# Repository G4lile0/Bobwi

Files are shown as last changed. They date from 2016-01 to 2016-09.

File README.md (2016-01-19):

# Bobwi

<b>Warning: This is a prototype, some parts need to be improved.</B>

Robot, inspired by Bob and Zowi, if you want more information regarding Zowi, please visit:
www.bq.com/zowi
http://diwo.bq.com/en/zowi-cc-by-sa/

If you want to replicate this dance:  https://youtu.be/4x4xa3OTv4A

First you need to calibrate the servos:
https://github.com/G4lile0/Bobwi/tree/master/code/v1/arduino/v1/calibration

Then use that values, to load the Dance code.
https://github.com/G4lile0/Bobwi/tree/master/code/v1/arduino/v1/smooth_criminal

If you want to control the robot from your Android phone: 

Download the official "Zowi App" from bq

Configure the bluetooth module using this code:
https://github.com/G4lile0/Bobwi/tree/master/code/v2/arduino/code/hc06_bt_config

Then load the Zowi base v2 software:
https://github.com/G4lile0/Bobwi/tree/master/code/v2/arduino/code/ZOWI_BASE_v2

##License



All these products are released under [Creative Commons Attribution-ShareAlike 4.0 International License](http://creativecommons.org/licenses/by-sa/4.0/).

Todos estos productos están liberados mediante [Creative Commons Attribution-ShareAlike 4.0 International License](http://creativecommons.org/licenses/by-sa/4.0/).

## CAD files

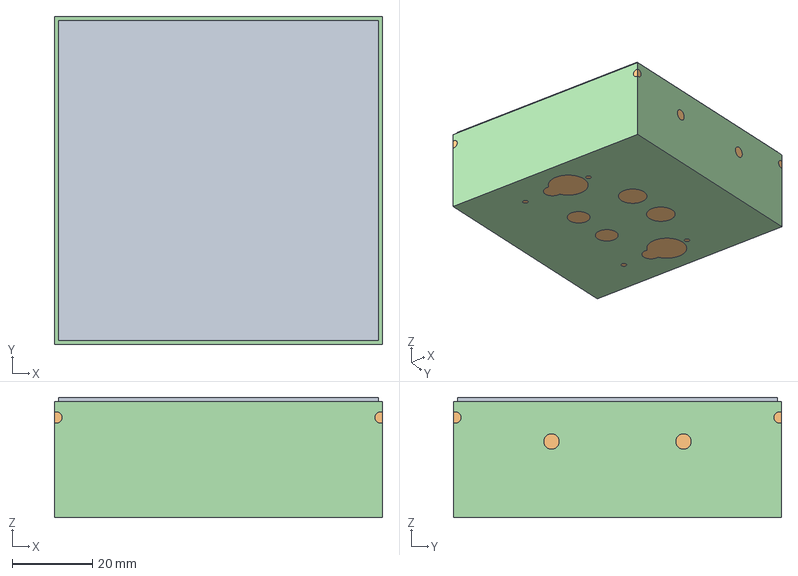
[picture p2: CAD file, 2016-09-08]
parts/freecad/base_matrix_led_v1_6.fcstd
82.0 x 82.0 x 30.0 mm
Box_int
Box_Ext
MONTEINO003

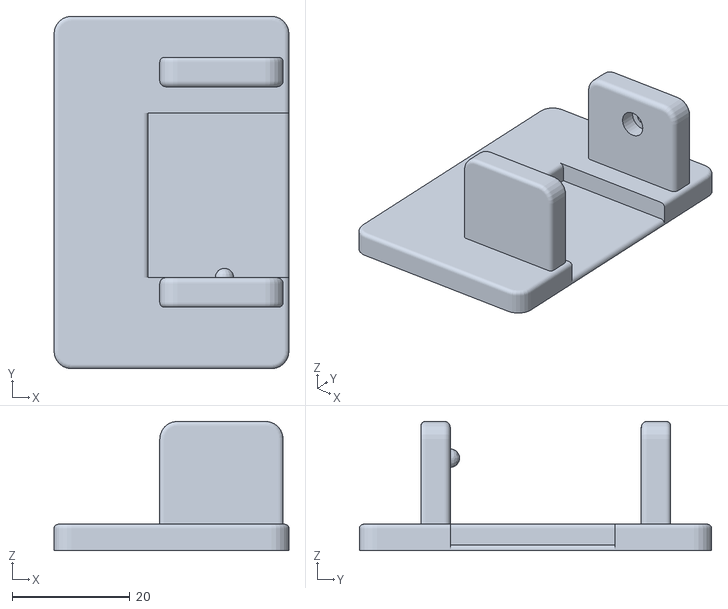
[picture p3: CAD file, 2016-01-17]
parts/stl/foot_v3_left.stl
40.0 x 60.0 x 22.0

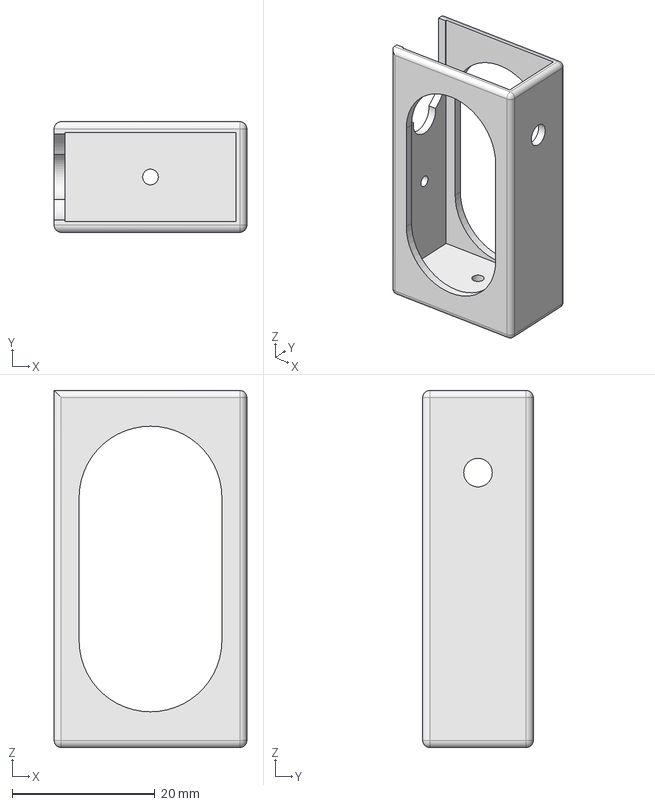
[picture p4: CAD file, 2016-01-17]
parts/freecad/leg_v5.fcstd
27.0 x 15.5 x 50.0 mm

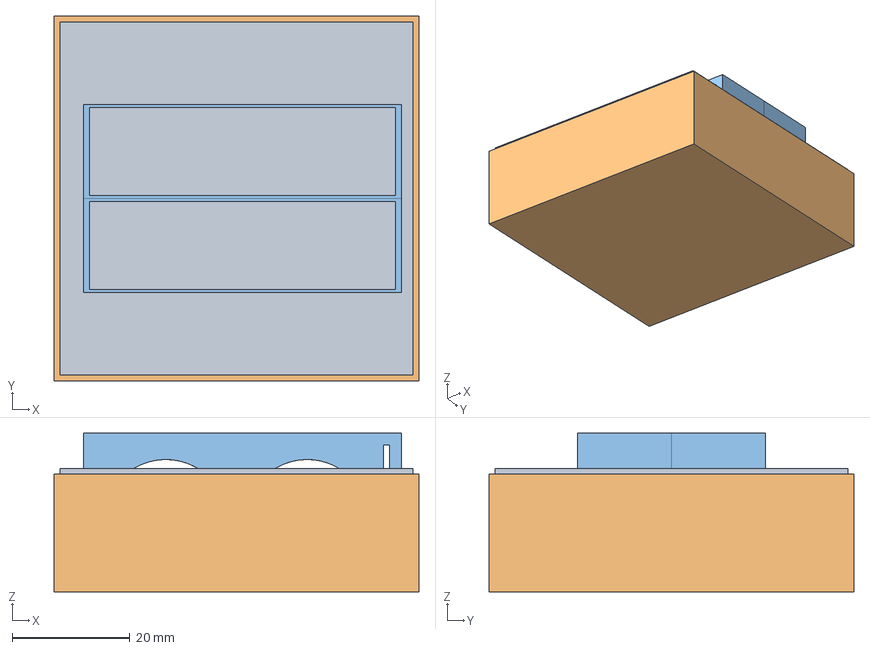
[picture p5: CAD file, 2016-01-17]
parts/freecad/base_v35.fcstd
62.0 x 62.0 x 27.0 mm
Box_int
Box_Ext

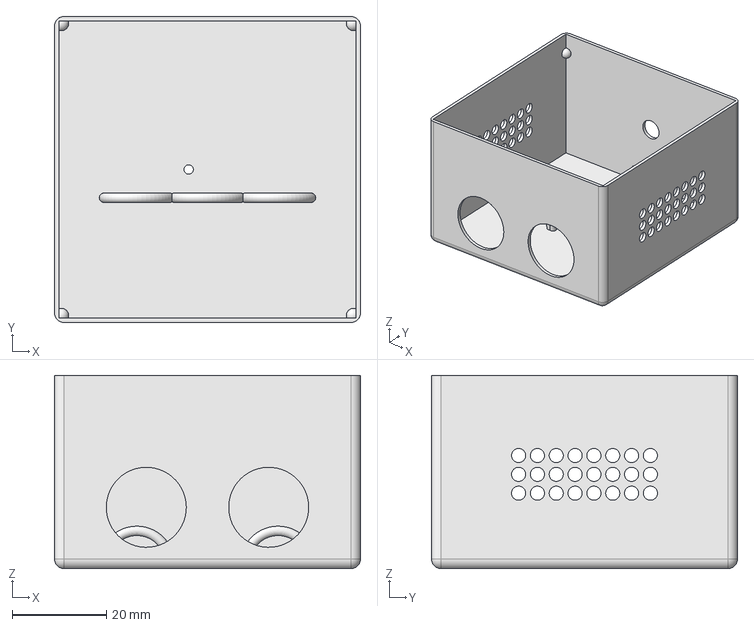
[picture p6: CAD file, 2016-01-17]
parts/freecad/head_v21.fcstd
65.0 x 65.0 x 41.0 mm

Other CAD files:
parts/stl/foot_v3_right.stl
parts/freecad/foot_v3.fcstd
parts/stl/base_matrix_led_v1_6.stl
parts/stl/base_v35.stl
parts/stl/head_v21.stl
parts/stl/leg_v5.stl

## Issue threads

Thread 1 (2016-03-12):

Instructions for assembly

JimSVMI83, 2016-03-12:
Awesome project I'm printing the parts now.  Can you provide assembly instructions or some detailed pictures of the insides.  Would save time in wiring together if not thanks anyway great job

Jim

dalcon, 2016-05-10:
He configurado el hc-06, con el softw propuesto, y en principio parece que todo bien, pero cuando abro la aplicación, empareja bien el dispositivo con bobwi, pero no hace ningun movimiento, como si no recibiera señal, ¿hay que hacer algun paso mas?

G4lile0, 2016-05-11:
Has probado a cargar el código del baile "Bobwi/code/v1/arduino/v1/smooth_criminal" .. mas que nada para comprobar que funcionen bien los servos..

Incluso sin conexión BT debería de moverse de forma aleatoria..

dalcon, 2016-05-11:
Si, los servos se mueven correctamente, cargandole las instrucciones a mano.
El problema es de comunicación.
De echo si monitorizo el puerto serie veo que envía el primer movimiento de la app zowi, M 1 100 correctamente, pero despues comienza a enviar solamente el caracter 'S'
con cualquier pulsación.

cparrapa, 2016-09-09:
Dalcon serán los Baudios? yo tengo el mismo problema primero use HC-06 por que el código era para eso y funciono!, luego cambie a un HC-05 como aparece en la lista de partes y me conecta pero no hay movimento :S

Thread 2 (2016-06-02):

Right Leg Servo doesn't move

cparrapa, 2016-06-02:
Hi G4lile0

Thanks  to other comments i make it work and connect easily with HC-06 Bluetooth module, but somehow the Right Leg Servo doesn't move (already double check different servos, the board and connections), also doesn't make sounds (buzzer pin 10). Is a little bit confusing the libraries of Zowi some of them have bugs and switching to Bitbloq generate some kind of redundancy in variables. Your libraries seems better for Bluetooth, are the last ones?

Overall great job! and thanks.

G4lile0, 2016-09-08:
Solved.. issue related to the different arduino pin configuration of Zowi and Bobwi,

Closed 2016-09-08.

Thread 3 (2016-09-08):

Chasis para matriz led

Ayunken, 2016-09-08:
Hola G4lile0.
He visto que has hecho una nueva base para la cabeza para añadir una matriz de leds en un video. Es posible que publiques los diseños 3D de la nueva cabeza. Gracias

G4lile0, 2016-09-08:
Muy buenas Ayunken,
Acabo de subir el modelo en FreeCAD y  STL de la base para la matriz de led, aunque aun no diseñado la parte superior...

Ayunken, 2016-09-08:
Gracias. como imprimiste los pies? porque la prominencia de la articulación se me imprime muy poco prominente, usaste soportes?

cparrapa, 2016-09-09:
Ayunken a mi me imprimió sin soportes al ser una semiesfera no necesita :)

Ayunken, 2016-09-09:
No veo claro el montaje del pie. Tienes algún detalle del montaje del mismo. Has usado alguna pieza más como las bielas del servo. Es que no me llega o algo estoy haciendo mal.

G4lile0, 2016-09-09:
El eje del servo tiene que entrar dentro del pie, entra algo duro, para que luego el eje no gire dentro del pie..  y la prominencia de la articulación entra justo en agujero de la pata.. a ver añado alguna foto.

Ayunken, 2016-09-09:
Infill 15%, pero el problema es que la pierna con el servo encajado en la prominencia (si no, no cabe porque tocaría al bascular en el hueco que hay en el ), pues el engranaje del servo no me llega al orificio del otro lado. Uso unos TowerPro SG90, los azules. Los del tuyo parecen blancos, igual son diferentes y tengo que adaptar los diseños. El orificio superior de la pierna para el servo alojado en la base-cabeza tampoco cabe, también es muy pequeño para el engranaje del servo, si no lo agrando con una lima...

Ayunken, 2016-09-09:
Ya veo que tus servos usados son los MG90, y sí que tendría que adaptar la pierna...

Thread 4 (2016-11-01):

Dudas con las conexiones

arodriguezf, 2016-11-01:
Hola,
revisando este proyecto y el de Brico3D, después de haber visto el código he entendido que irían así las conexiones:
Según lo que pude entender por el código, me puedes confirmar si este es tu plano de conexiones?
0 RX -> HC-06 TX
1 TX -> HC-06 RX
2 - NADA
3 - YR
4 - RL
5 - RR
6 - YL
7 - Third Button (como iría conectado?)
8 - Trigger
9 - Echo
10 - NADA
11 - LED Matrix SER
12 - LED Matrix RCK
13 - LED Matrix CLK
14 (A0?) - Third Button (como iría conectado?) -> Brico3D comenta que tuvo que poner un cable en A0 a modo de antena por recomendación tuya, a que se debe esto y como se debería conectar?
A2 - Buzzer
A6 - Noise detection
A7 - Información sobre batería

Podrías confirmarme estas dudas y como lo tienes tu conectado?

Un saludo

hulkco, 2016-11-01:
Solo enchufa(conecta) un cable y dejalo al aire, to use un cable con conector hembra y recorte el otro extremo [imagen](https://statics3.seeedstudio.com/images/product/jw100n.jpg)

arodriguezf, 2016-11-01:
Muchas gracias por responder, he hecho lo del cable pero aún así no responde a la app, se conecta correctamente, al pulsar una orden en la app parpadea el led de RX en el arduino pero no se mueve, alguna idea?

hulkco, 2016-11-01:
A que pin lo estas conectando? yo estoy usando el skecth de BobWi y el pin A0.

hulkco, 2016-11-01:
Tambien debes configurar tu bluettoh usando los skectch que proporciona BobWi

arodriguezf, 2016-11-01:
El cable lo he puesto en el A0 pero he probado en todos los AX libres, el bluetooth lo tengo configurado con el skectch para el hc-05 y consico conectarlo a la app de zowi

hulkco, 2016-11-01:
ok intenta tocando con los dedos los pines 6 y 7  y verifica qeu tengas este cambio:

//---Zowi Buttons original dos 6 tres 7
#define PIN_SecondButton A0
#define PIN_ThirdButton 7

arodriguezf, 2016-11-01:
he estado probando de nuevo (pero esta vez de forma manual) a configurar el HC-05 y ahora si que va.
En cuanto a los botones los tengo así y funciona:
#define PIN_SecondButton 14
#define PIN_ThirdButton 7

Muchas gracias!

mrslide555, 2016-12-31:
hola, todos utilizáis esa matriz de led?? la MAX7219 yo tengo una matriz de keystudio con conexión I2C y la verdad que me estoy haciendo un lío, no se muy bien a que pines hay que conectarla.. En principio elegí esa porque Galile0 hizo una conversión y pensé que iría mejor.. alguien me ayuda? gracias :)

ideasconsentidocomun, 2017-03-01:
hola arodriguezf tengo el mismo problema la con el hc-05 la app se conecta pero no se mueve como lo solucionaste....HELP

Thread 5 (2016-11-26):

Battery problem

sicay1, 2016-11-26:
Hi All,
Anyone got battery problem like me. With cheap 4x AA battery, bluetooth HC-06 not running (no power). With 4x AA Energizer Bobwi can only run about 1 hour and then HC-06 not running (like cheap battery)

My Bobwi part:
1. Arduino nano
2. nano shield
3. bluetooth HC06
4. servo 9g x4
5. Battery AA x4 (picture http://media.vatgia.vn/ir_type6/zjf1295920515.jpg)

I was using this code:
Control the robot from your Android phone:
Download the official "Zowi App" from bq
Configure the bluetooth module using this code: https://github.com/G4lile0/Bobwi/tree/master/code/v2/arduino/code/hc06_bt_config
Then load the Zowi base v2 software: https://github.com/G4lile0/Bobwi/tree/master/code/v2/arduino/code/ZOWI_BASE_v2

Tony .

poyaque-estamos, 2016-11-27:
Cant' really answer about batteries since I haven't even connected mine yet. But what goes for usb connection I can tell you it is also very sensitive to it. I can only make it work with the cable that came with the arduino and connected to the computer. Any other combinations of cable/source don't work.

More in detail, when i mean work, i mean being able to control it from the zowi app. For example, I can connect it via usb to a usb charger and the robot might seem to normally start, but it doesn't answer to the app correctly (the app says it is connected though). In other cases it doesn't even start correctly at all and the app doesn't show it as connected either.

G4lile0, 2016-11-27:
Servos consume a lot, and drop the battery voltage under 5V or 3,3V and reset the arduino, to solve this add this circuit:
              
                         ------ Servos
                         |  
+ Battery  -------+-------->|--------+---------------------- 5V arduino.
                                 diode        |
                                               ===  Capacitor 1000uF /10V
                                                  |
- Battery   ---- GND------------------------------------- GND arduino

In order to make Bobwi work to the app, you have add a button for A0, or just a single wire, and touch it, to make Bobwi change to app mode.

edmondhuang, 2016-11-28:
Hi All,

There should be problem with Nano Sheild, it can't go through big currents, I think. What my solution is as below.

* 5V power supply directly, using LiPo battery with 5V/4A rise circuit.

sicay1, 2016-11-29:
many thanks, G4lile0.
Haven't try you diagram yet, need to learn more basic electronics, circuits.

@poyaque-estamos i got no problem when using USB cable control Bobwi over bluetooth

Closed 2016-11-29.

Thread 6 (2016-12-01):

error cargar

mrslide555, 2016-12-01:
hola, quiero probar a montar un zowi, pero me dice que el archivo es muy grande... ¿que hago mal? ¿me podéis ayudar? Gracias

Tamaño binario del Sketch: 32.584 bytes (de un máximo de 30.720 bytes)
processing.app.debug.RunnerException: Sketch demasiado grande; ver http://www.arduino.cc/en/Guide/Troubleshooting#size para consejos de como reducirlo.
	at processing.app.Sketch.size(Sketch.java:1653)
	at processing.app.Sketch.build(Sketch.java:1586)
	at processing.app.Sketch.build(Sketch.java:1562)
	at processing.app.Editor$DefaultRunHandler.run(Editor.java:1899)
	at java.lang.Thread.run(Thread.java:619)

hulkco, 2016-12-04:
Que Tarjeta, y IDE Arduino usas y que Programa quieres subir?

mrslide555, 2016-12-07:
Ya está solucionado, el problema era la versión del arduino, ha bastado con actualizar y volver a compilar.

¿Esta versión lleva microfono?? He visto otro que ha montado su zowi y le ha añadido micrófono..  Supongo que será para el modo 4..

hulkco, 2016-12-08:
Todavia no intento lo del microfono, llegue hasta buzzer

mrslide555, 2016-12-11:
Socorro !! tengo otro problema, meto el codigo en el arduino nano y no hay manera hace pausas, va a trompicones ¿puede ser que me hayan vendido unos arduino lentos? en principio los compre como nano 328. ¿se te ocurre cual es el problema??

gracias

mrslide555, 2016-12-31:
Ya esta Solucionado, era todo cosa de las baterías, necesita mucha corriente!! Gracias

hulkco, 2017-01-01:
jejeje, a mi tambien me trajo loco ese problema, yo uso una de 9v Recargable, es mas comodo, saludos, tenemos un grupo en Telegram, #RetoBaileZowi aun estas a tiempo de ingresar y compartir Saludos y Feliz Año.!

lobras77, 2021-02-15:
Hola. Saqué las piezas con la impresora e iba a conectarlo todo cuando me ha sorprendido que no me compila y no entiendo el porqué. Guardé las librerías en la carpeta y usé el codigo del zowi_base_v2  . Me puede ayudar alguien?

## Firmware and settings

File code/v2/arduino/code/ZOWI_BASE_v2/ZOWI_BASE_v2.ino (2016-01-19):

//----------------------------------------------------------------
//-- Zowi basic firmware v2
//-- (c) BQ. Released under a GPL licencse
//-- 04 December 2015
//-- Authors:  Anita de Prado: ana.deprado@bq.com
//--           Jose Alberca:   jose.alberca@bq.com
//--           Javier Isabel:  javier.isabel@bq.com
//--           Juan Gonzalez (obijuan): juan.gonzalez@bq.com
//--           Irene Sanz : irene.sanz@bq.com
//-----------------------------------------------------------------
//-- Experiment with all the features that Zowi have!
//-----------------------------------------------------------------

#include <Servo.h> 
#include <Oscillator.h>
#include <EEPROM.h>
#include <BatReader.h>
#include <US.h>
#include <LedMatrix.h>

//-- Library to manage external interruptions
#include <EnableInterrupt.h> 

//-- Library to manage serial commands
#include <ZowiSerialCommand.h>
ZowiSerialCommand SCmd;  //The SerialCommand object

//-- Zowi Library
#include <Zowi.h>
Zowi zowi;  //This is Zowi!!
 
//---------------------------------------------------------
//-- Configuration of pins where the servos are attached
/*
         --------------- 
        |               |
        |     O   O     |
        |               |
 YR ==> |               | <== YL
         --------------- 
            ||     ||
            ||     ||
            ||     ||
 RR ==>   -----   ------  <== RL
          -----   ------
*/

  #define PIN_YL 6 //servo[0]
  #define PIN_YR 3 //servo[1]
  #define PIN_RL 4 //servo[2]
  #define PIN_RR 5 //servo[3]
  
//---------------------------------------------------------

//---Zowi Buttons original dos 6 tres 7
#define PIN_SecondButton 14
#define PIN_ThirdButton 7


///////////////////////////////////////////////////////////////////
//-- Global Variables -------------------------------------------//
///////////////////////////////////////////////////////////////////

const char programID[]="ZOWI_BASE_v2"; //Each program will have a ID

const char name_fac='$'; //Factory name
const char name_fir='#'; //First name

//-- Movement parameters
int T=1000;              //Initial duration of movement
int moveId=0;            //Number of movement
int moveSize=15;         //Asociated with the height of some movements

//---------------------------------------------------------
//-- Zowi has 5 modes:
//--    * MODE = 0: Zowi is awaiting  
//--    * MODE = 1: Dancing mode!  
//--    * MODE = 2: Obstacle detector mode  
//--    * MODE = 3: Noise detector mode   
//--    * MODE = 4: ZowiPAD or any Teleoperation mode (listening SerialPort). 
//--
volatile int MODE=0; //State of zowi in the principal state machine. 
//--------------------------------------------------------- 

volatile bool buttonPushed=false;  //Variable to remember when a button has been pushed
volatile bool buttonAPushed=false; //Variable to remember when A button has been pushed
volatile bool buttonBPushed=false; //Variable to remember when B button has been pushed

unsigned long previousMillis=0;

int randomDance=0;
int randomSteps=0;

bool obstacleDetected = false;


///////////////////////////////////////////////////////////////////
//-- Setup ------------------------------------------------------//
///////////////////////////////////////////////////////////////////
void setup(){

  //Serial communication initialization
  Serial.begin(115200);  

  pinMode(PIN_SecondButton,INPUT);
  pinMode(PIN_ThirdButton,INPUT);
  
  //Set the servo pins
  zowi.init(PIN_YL,PIN_YR,PIN_RL,PIN_RR,true);
 
  //Uncomment this to set the servo trims manually and save on EEPROM 
    //zowi.setTrims(TRIM_YL, TRIM_YR, TRIM_RL, TRIM_RR);
    //zowi.saveTrimsOnEEPROM(); //Uncomment this only for one upload when you finaly set the trims.

  //Set a random seed
  randomSeed(analogRead(A6));

  //Interrumptions
  enableInterrupt(PIN_SecondButton, secondButtonPushed, RISING);
  enableInterrupt(PIN_ThirdButton, thirdButtonPushed, RISING);

  //Setup callbacks for SerialCommand commands 
  SCmd.addCommand("S", receiveStop);      //  sendAck & sendFinalAck
  SCmd.addCommand("L", receiveLED);       //  sendAck & sendFinalAck
  SCmd.addCommand("T", recieveBuzzer);    //  sendAck & sendFinalAck
  SCmd.addCommand("M", receiveMovement);  //  sendAck & sendFinalAck
  SCmd.addCommand("H", receiveGesture);   //  sendAck & sendFinalAck
  SCmd.addCommand("K", receiveSing);      //  sendAck & sendFinalAck
  SCmd.addCommand("C", receiveTrims);     //  sendAck & sendFinalAck
  SCmd.addCommand("G", receiveServo);     //  sendAck & sendFinalAck
  SCmd.addCommand("R", receiveName);      //  sendAck & sendFinalAck
  SCmd.addCommand("E", requestName);
  SCmd.addCommand("D", requestDistance);
  SCmd.addCommand("N", requestNoise);
  SCmd.addCommand("B", requestBattery);
  SCmd.addCommand("I", requestProgramId);
  SCmd.addDefaultHandler(receiveStop);



  //Zowi wake up!
  zowi.sing(S_connection);
  zowi.home();


  //If Zowi's name is '&' (factory name) means that is the first time this program is executed.
  //This first time, Zowi mustn't do anything. Just born at the factory!
  //5 = EEPROM address that contains first name character
  if (EEPROM.read(5)==name_fac){ 

    EEPROM.put(5, name_fir); //From now, the name is '#'
    EEPROM.put(6, '\0'); 
    zowi.putMouth(culito);

    while(true){    
       delay(1000);
    }
  }  


  //Send Zowi name, programID & battery level.
  requestName();
  delay(50);
  requestProgramId();
  delay(50);
  requestBattery();
  
  //Checking battery
  ZowiLowBatteryAlarm();


 // Animation Uuuuuh - A little moment of initial surprise
 //-----
  for(int i=0; i<2; i++){
      for (int i=0;i<8;i++){
        if(buttonPushed){break;}  
        zowi.putAnimationMouth(littleUuh,i);
        delay(150);
      }
  }
 //-----


  //Smile for a happy Zowi :)
  if(!buttonPushed){ 
    zowi.putMouth(smile);
    zowi.sing(S_happy);
    delay(200);
  }


  //If Zowi's name is '#' means that Zowi hasn't been baptized
  //In this case, Zowi does a longer greeting
  //5 = EEPROM address that contains first name character
  if (EEPROM.read(5)==name_fir){ 

    if(!buttonPushed){  
        zowi.jump(1,700);
        delay(200); 
    }

    if(!buttonPushed){  
        zowi.shakeLeg(1,T,1); 
    }  
    
    if(!buttonPushed){ 
        zowi.putMouth(smallSurprise);
        zowi.swing(2,800,20);  
        zowi.home();
    }  
  }


  if(!buttonPushed){ 
    zowi.putMouth(happyOpen);
  }

  previousMillis = millis();

}



///////////////////////////////////////////////////////////////////
//-- Principal Loop ---------------------------------------------//
///////////////////////////////////////////////////////////////////
void loop() {


  if (Serial.available()>0 && MODE!=4){

    MODE=4;
    zowi.putMouth(happyOpen);

    //Disable Pin Interruptions
    disableInterrupt(PIN_SecondButton);
    disableInterrupt(PIN_ThirdButton);

    buttonPushed=false;
  }


  //First attemp to initial software
  if (buttonPushed){  

    zowi.home();

    delay(100); //Wait for all buttons 
    zowi.sing(S_buttonPushed);
    delay(200); //Wait for all buttons 

    if      ( buttonAPushed && !buttonBPushed){ MODE=1; zowi.sing(S_mode1);}
    else if (!buttonAPushed && buttonBPushed) { MODE=2; zowi.sing(S_mode2);}
    else if ( buttonAPushed && buttonBPushed) { MODE=3; zowi.sing(S_mode3);} //else

    zowi.putMouth(MODE);
 
    int showTime = 2000;
    while((showTime>0)){ //Wait to show the MODE number 
        
        showTime-=10;
        delay(10);
    }
     
    zowi.putMouth(happyOpen);

    buttonPushed=false;
    buttonAPushed=false;
    buttonBPushed=false;

  }else{

    switch (MODE) {

      //-- MODE 0 - Zowi is awaiting
      //---------------------------------------------------------
      case 0:
      
        //Every 80 seconds in this mode, Zowi falls asleep 
        if (millis()-previousMillis>=80000){
            ZowiSleeping_withInterrupts(); //ZZzzzzz...
            previousMillis=millis();         
        }

        break;
      

      //-- MODE 1 - Dance Mode!
      //---------------------------------------------------------
      case 1:
        
        randomDance=random(5,21); //5,20
        if((randomDance>14)&&(randomDance<19)){
            randomSteps=1;
            T=1600;
        }
        else{
            randomSteps=random(3,6); //3,5
            T=1000;
        }
        
        zowi.putMouth(random(10,21));

        for (int i=0;i<randomSteps;i++){
            move(randomDance);
            if(buttonPushed){break;}
        }
        break;


      //-- MODE 2 - Obstacle detector mode
      //---------------------------------------------------------
      case 2:

        if(obstacleDetected){

            if(!buttonPushed){
              zowi.putMouth(bigSurprise);
              zowi.sing(S_surprise);
              zowi.jump(5, 500);
            }  

            if(!buttonPushed){
              zowi.putMouth(confused);
              zowi.sing(S_cuddly);
            }  

            //Zowi takes two steps back
            for(int i=0;i<3;i++){ 
              if(buttonPushed){break;}
              zowi.walk(1,1300,-1);
            }

            delay(100);
            obstacleDetector();
            delay(100);


           //If there are no obstacles and no button is pressed, Zowi shows a smile
           if((obstacleDetected==true)||(buttonPushed==true)){break;}            
           else{
              zowi.putMouth(smile);
              delay(50);
              obstacleDetector();
           } 
            
           
           //If there are no obstacles and no button is pressed, Zowi shows turns left
           for(int i=0; i<3; i++){
              if((obstacleDetected==true)||(buttonPushed==true)){break;}            
              else{ 
                  zowi.turn(1,1000,1); 
                  obstacleDetector();
              } 
           }
            
            //If there are no obstacles and no button is pressed, Zowi is happy
            if((obstacleDetected==true)||(buttonPushed==true)){break;}           
            else{
                zowi.home();
                zowi.putMouth(happyOpen);
                zowi.sing(S_happy_short);
                delay(200);
            }     
        

        }else{

            zowi.walk(1,1000,1); //Zowi walk straight
            obstacleDetector();
        }   

        break;


      //-- MODE 3 - Noise detector mode
      //---------------------------------------------------------  
      case 3:
        if (zowi.getNoise()>=650){ //740
          
          delay(50);  //Wait for the possible 'lag' of the button interruptions. 
                      //Sometimes, the noise sensor detect the button before the interruption takes efect 
          
          if(!buttonPushed){

            zowi.putMouth(bigSurprise);
            zowi.sing(S_OhOoh);

            if(buttonPushed){break;}
            zowi.putMouth(random(10,21));
            randomDance=random(5,21);
            move(randomDance);
            zowi.home();
            delay(500); //Wait for possible noise of the servos while get home
          }
          
          if(!buttonPushed){zowi.putMouth(happyOpen);}
        }
        break;
        

      //-- MODE 4 - ZowiPAD or any Teleoperation mode (listening SerialPort) 
      //---------------------------------------------------------
      case 4:

        SCmd.readSerial();
        
        //If Zowi is moving yet
        if (zowi.getRestState()==false){  
          move(moveId);
        }
      
        break;      


      default:
          MODE=4;
          break;
    }

  } 

}  



///////////////////////////////////////////////////////////////////
//-- Functions --------------------------------------------------//
///////////////////////////////////////////////////////////////////

//-- Function executed when second button is pushed
void secondButtonPushed(){ 

    buttonAPushed=true;

    if(!buttonPushed){
        buttonPushed=true;
        zowi.putMouth(smallSurprise);
    }    
}

//-- Function executed when third button is pushed
void thirdButtonPushed(){ 

    buttonBPushed=true;

    if(!buttonPushed){
        buttonPushed=true;
        zowi.putMouth(smallSurprise);
    }
}


//-- Function to read distance sensor & to actualize obstacleDetected variable
void obstacleDetector(){

   int distance = zowi.getDistance();

        if(distance<15){
          obstacleDetected = true;
        }else{
          obstacleDetected = false;
        }
}


//-- Function to receive Stop command.
void receiveStop(){

    sendAck();
    zowi.home();
    sendFinalAck();

}


//-- Function to receive LED commands
void receiveLED(){  

    //sendAck & stop if necessary
    sendAck();
    zowi.home();

    //Examples of receiveLED Bluetooth commands
    //L 000000001000010100100011000000000
    //L 001111111111111111111111111111111 (todos los LED encendidos)
    unsigned long int matrix;
    char *arg;
    char *endstr;
    arg=SCmd.next();
    //Serial.println (arg);
    if (arg != NULL) {
      matrix=strtoul(arg,&endstr,2);    // Converts a char string to unsigned long integer
      zowi.putMouth(matrix,false);
    }else{
      zowi.putMouth(xMouth);
      delay(2000);
      zowi.clearMouth();
    }

    sendFinalAck();

}


//-- Function to receive buzzer commands
void recieveBuzzer(){
  
    //sendAck & stop if necessary
    sendAck();
    zowi.home(); 

    bool error = false; 
    int frec;
    int duration; 
    char *arg; 
    
    arg = SCmd.next(); 
    if (arg != NULL) { frec=atoi(arg); }    // Converts a char string to an integer   
    else {error=true;}
    
    arg = SCmd.next(); 
    if (arg != NULL) { duration=atoi(arg); } // Converts a char string to an integer  
    else {error=true;}

    if(error==true){

      zowi.putMouth(xMouth);
      delay(2000);
      zowi.clearMouth();

    }else{ 

      zowi._tone(frec, duration, 1);   
    }

    sendFinalAck();

}


//-- Function to receive TRims commands
void receiveTrims(){  

    //sendAck & stop if necessary
    sendAck();
    zowi.home(); 

    int trim_YL,trim_YR,trim_RL,trim_RR;

    //Definition of Servo Bluetooth command
    //C trim_YL trim_YR trim_RL trim_RR
    //Examples of receiveTrims Bluetooth commands
    //C 20 0 -8 3
    bool error = false;
    char *arg;
    arg=SCmd.next();
    if (arg != NULL) { trim_YL=atoi(arg); }    // Converts a char string to an integer   
    else {error=true;}

    arg = SCmd.next(); 
    if (arg != NULL) { trim_YR=atoi(arg); }    // Converts a char string to an integer  
    else {error=true;}

    arg = SCmd.next(); 
    if (arg != NULL) { trim_RL=atoi(arg); }    // Converts a char string to an integer  
    else {error=true;}

    arg = SCmd.next(); 
    if (arg != NULL) { trim_RR=atoi(arg); }    // Converts a char string to an integer  
    else {error=true;}
    
    if(error==true){

      zowi.putMouth(xMouth);
      delay(2000);
      zowi.clearMouth();

    }else{ //Save it on EEPROM
      zowi.setTrims(trim_YL, trim_YR, trim_RL, trim_RR);
      zowi.saveTrimsOnEEPROM(); //Uncomment this only for one upload when you finaly set the trims.
    } 

    sendFinalAck();

}


//-- Function to receive Servo commands
void receiveServo(){  

    sendAck(); 
    moveId = 30;

    //Definition of Servo Bluetooth command
    //G  servo_YL servo_YR servo_RL servo_RR 
    //Example of receiveServo Bluetooth commands
    //G 90 85 96 78 
    bool error = false;
    char *arg;
    int servo_YL,servo_YR,servo_RL,servo_RR;

    arg=SCmd.next();
    if (arg != NULL) { servo_YL=atoi(arg); }    // Converts a char string to an integer   
    else {error=true;}

    arg = SCmd.next(); 
    if (arg != NULL) { servo_YR=atoi(arg); }    // Converts a char string to an integer  
    else {error=true;}

    arg = SCmd.next(); 
    if (arg != NULL) { servo_RL=atoi(arg); }    // Converts a char string to an integer  
    else {error=true;}

    arg = SCmd.next(); 
    if (arg != NULL) { servo_RR=atoi(arg); }    // Converts a char string to an integer  
    else {error=true;}
    
    if(error==true){

      zowi.putMouth(xMouth);
      delay(2000);
      zowi.clearMouth();

    }else{ //Update Servo:

      int servoPos[4]={servo_YL, servo_YR, servo_RL, servo_RR}; 
      zowi._moveServos(200, servoPos);   //Move 200ms
      
    }

    sendFinalAck();

}


//-- Function to receive movement commands
void receiveMovement(){

    sendAck();

    if (zowi.getRestState()==true){
        zowi.setRestState(false);
    }

    //Definition of Movement Bluetooth commands
    //M  MoveID  T   MoveSize  
    char *arg; 
    arg = SCmd.next(); 
    if (arg != NULL) {moveId=atoi(arg);}
    else{
      zowi.putMouth(xMouth);
      delay(2000);
      zowi.clearMouth();
      moveId=0; //stop
    }
    
    arg = SCmd.next(); 
    if (arg != NULL) {T=atoi(arg);}
    else{
      T=1000;
    }

    arg = SCmd.next(); 
    if (arg != NULL) {moveSize=atoi(arg);}
    else{
      moveSize =15;
    }
}


//-- Function to execute the right movement according the movement command received.
void move(int moveId){

  bool manualMode = false;

  switch (moveId) {
    case 0:
      zowi.home();
      break;
    case 1: //M 1 1000 
      zowi.walk(1,T,1);
      break;
    case 2: //M 2 1000 
      zowi.walk(1,T,-1);
      break;
    case 3: //M 3 1000 
      zowi.turn(1,T,1);
      break;
    case 4: //M 4 1000 
      zowi.turn(1,T,-1);
      break;
    case 5: //M 5 1000 30 
      zowi.updown(1,T,moveSize);
      break;
    case 6: //M 6 1000 30
      zowi.moonwalker(1,T,moveSize,1);
      break;
    case 7: //M 7 1000 30
      zowi.moonwalker(1,T,moveSize,-1);
      break;
    case 8: //M 8 1000 30
      zowi.swing(1,T,moveSize);
      break;
    case 9: //M 9 1000 30 
      zowi.crusaito(1,T,moveSize,1);
      break;
    case 10: //M 10 1000 30 
      zowi.crusaito(1,T,moveSize,-1);
      break;
    case 11: //M 11 1000 
      zowi.jump(1,T);
      break;
    case 12: //M 12 1000 30 
      zowi.flapping(1,T,moveSize,1);
      break;
    case 13: //M 13 1000 30
      zowi.flapping(1,T,moveSize,-1);
      break;
    case 14: //M 14 1000 20
      zowi.tiptoeSwing(1,T,moveSize);
      break;
    case 15: //M 15 500 
      zowi.bend(1,T,1);
      break;
    case 16: //M 16 500 
      zowi.bend(1,T,-1);
      break;
    case 17: //M 17 500 
      zowi.shakeLeg(1,T,1);
      break;
    case 18: //M 18 500 
      zowi.shakeLeg(1,T,-1);
      break;
    case 19: //M 19 500 20
      zowi.jitter(1,T,moveSize);
      break;
    case 20: //M 20 500 15
      zowi.ascendingTurn(1,T,moveSize);
      break;
    default:
        manualMode = true;
      break;
  }

  if(!manualMode){
    sendFinalAck();
  }
       
}


//-- Function to receive gesture commands
void receiveGesture(){

    //sendAck & stop if necessary
    sendAck();
    zowi.home(); 

    //Definition of Gesture Bluetooth commands
    //H  GestureID  
    int gesture = 0;
    char *arg; 
    arg = SCmd.next(); 
    if (arg != NULL) {gesture=atoi(arg);}
    else 
    {
      zowi.putMouth(xMouth);
      delay(2000);
      zowi.clearMouth();
    }

    switch (gesture) {
      case 1: //H 1 
        zowi.playGesture(ZowiHappy);
        break;
      case 2: //H 2 
        zowi.playGesture(ZowiSuperHappy);
        break;
      case 3: //H 3 
        zowi.playGesture(ZowiSad);
        break;
      case 4: //H 4 
        zowi.playGesture(ZowiSleeping);
        break;
      case 5: //H 5  
        zowi.playGesture(ZowiFart);
        break;
      case 6: //H 6 
        zowi.playGesture(ZowiConfused);
        break;
      case 7: //H 7 
        zowi.playGesture(ZowiLove);
        break;
      case 8: //H 8 
        zowi.playGesture(ZowiAngry);
        break;
      case 9: //H 9  
        zowi.playGesture(ZowiFretful);
        break;
      case 10: //H 10
        zowi.playGesture(ZowiMagic);
        break;  
      case 11: //H 11
        zowi.playGesture(ZowiWave);
        break;   
      case 12: //H 12
        zowi.playGesture(ZowiVictory);
        break; 
      case 13: //H 13
        zowi.playGesture(ZowiFail);
        break;         
      default:
        break;
    }

    sendFinalAck();
}

//-- Function to receive sing commands
void receiveSing(){

    //sendAck & stop if necessary
    sendAck();
    zowi.home(); 

    //Definition of Sing Bluetooth commands
    //K  SingID    
    int sing = 0;
    char *arg; 
    arg = SCmd.next(); 
    if (arg != NULL) {sing=atoi(arg);}
    else 
    {
      zowi.putMouth(xMouth);
      delay(2000);
      zowi.clearMouth();
    }

    switch (sing) {
      case 1: //K 1 
        zowi.sing(S_connection);
        break;
      case 2: //K 2 
        zowi.sing(S_disconnection);
        break;
      case 3: //K 3 
        zowi.sing(S_surprise);
        break;
      case 4: //K 4 
        zowi.sing(S_OhOoh);
        break;
      case 5: //K 5  
        zowi.sing(S_OhOoh2);
        break;
      case 6: //K 6 
        zowi.sing(S_cuddly);
        break;
      case 7: //K 7 
        zowi.sing(S_sleeping);
        break;
      case 8: //K 8 
        zowi.sing(S_happy);
        break;
      case 9: //K 9  
        zowi.sing(S_superHappy);
        break;
      case 10: //K 10
        zowi.sing(S_happy_short);
        break;  
      case 11: //K 11
        zowi.sing(S_sad);
        break;   
      case 12: //K 12
        zowi.sing(S_confused);
        break; 
      case 13: //K 13
        zowi.sing(S_fart1);
        break;
      case 14: //K 14
        zowi.sing(S_fart2);
        break;
      case 15: //K 15
        zowi.sing(S_fart3);
        break;    
      case 16: //K 16
        zowi.sing(S_mode1);
        break; 
      case 17: //K 17
        zowi.sing(S_mode2);
        break; 
      case 18: //K 18
        zowi.sing(S_mode3);
        break;   
      case 19: //K 19
        zowi.sing(S_buttonPushed);
        break;                      
      default:
        break;
    }

    sendFinalAck();
}
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

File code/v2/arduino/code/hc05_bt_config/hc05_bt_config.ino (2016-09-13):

/*
	Configuración de modulo Bluetooth HC-05 para funcionar con la aplicacion de Zowi
	
	Based on the sketch from giltesa.com
	http://giltesa.com/?p=11738
	and the sketch an info from 
	http://www.techbitar.com/modify-the-hc-05-bluetooth-module-defaults-using-at-commands.html
	Licencia:		 (CC) BY-NC-SA: giltesa.com

	El siguiente código permite configurar el modulo Bluetooth HC-05 desde Arduino.
	Se puede ajustar el nombre, la contraseña y los baudios a usar con el puerto serie.
	La configuración Bluetooth se guarda en el modulo, así que solo es necesario configurarlo una vez.
	
	Después de grabar el programa en el Arduino se dispone de 10 segundos de tiempo para conectar el
	modulo, una vez se apague el led comenzara el proceso de configuración y al terminar el led comenzara
	a parpadear.
	
	** La configuración se ha de hacer con el modulo sin emparejar (sin conectar con nada) **


	WIRING

    	HC-05 GND          --- Arduino GND Pin
    	HC-05 VCC (5V)     --- Arduino 5V
    	HC-05 TX           --- Arduino Pin 10 (soft RX)
    	HC-05 RX           --- Arduino Pin11 (soft TX)
    	HC-05 Key (PIN 34) --- Arduino Pin 9


*/



#include <SoftwareSerial.h>

SoftwareSerial BTSerial(10, 11); // RX | TX


void setup()
{

	pinMode(9, OUTPUT);  // this pin will pull the HC-05 pin 34 (key pin) HIGH to switch module to AT mode
  digitalWrite(9, HIGH);
  Serial.begin(9600);
  Serial.println("Enter AT commands:");
  BTSerial.begin(38400);  // HC-05 default speed in AT command more
	
	// Tiempo de espera:
		pinMode(9,OUTPUT);
		digitalWrite(9,HIGH);
		delay(10000);
		digitalWrite(9,LOW);
	
	
	// Ahora se procede a la configuración del modulo:
	
		// Se inicia la configuración:
			Serial.print("AT"); delay(1000);

		// Se ajusta el nombre del Bluetooth:
			Serial.println("AT+NAME=ZOWI"); delay(1000);

		// Se ajustan los baudios:
			Serial.println("AT+UART=115200,1,0"); delay(1000);

		// Se ajusta la contraseña:
			Serial.println("AT+PSWD=2987");  delay(1000);	

}

void loop()
{
	// Al parpadear el led se habrá terminado la configuración:
	digitalWrite(9, !digitalRead(9));
	delay(500);
}

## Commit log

2016-01-17 FreeCAD files
    [base_v35.fcstd, foot_v3.fcstd, head_v21.fcstd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]
2016-01-17 main upload
    [base_v35.stl, foot_v3_left.stl, foot_v3_right.stl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]
2016-01-24 added correct pin for the buzzer
    [Zowi.h]
2016-04-27 added new library adaptec to work with i2c Matrix (Adafruit Mini 8x8 LED Matrix w/I2C Backpack - Ultra Bright White) PRODUCT ID: 1080
2016-09-08 add base_matrix_led
    [base_matrix_led_v1_6.fcstd, base_matrix_led_v1_6.stl]
